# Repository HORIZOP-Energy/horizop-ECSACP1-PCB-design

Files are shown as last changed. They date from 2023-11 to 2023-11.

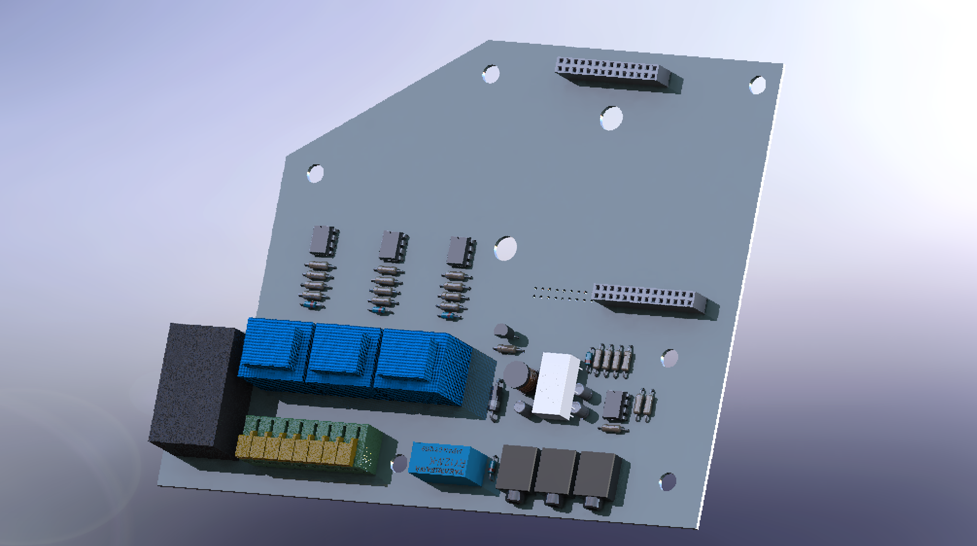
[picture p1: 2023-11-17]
Renders/Assembly_HE_ECSACP1_Prototype_PCB_V9_Final_Render.png

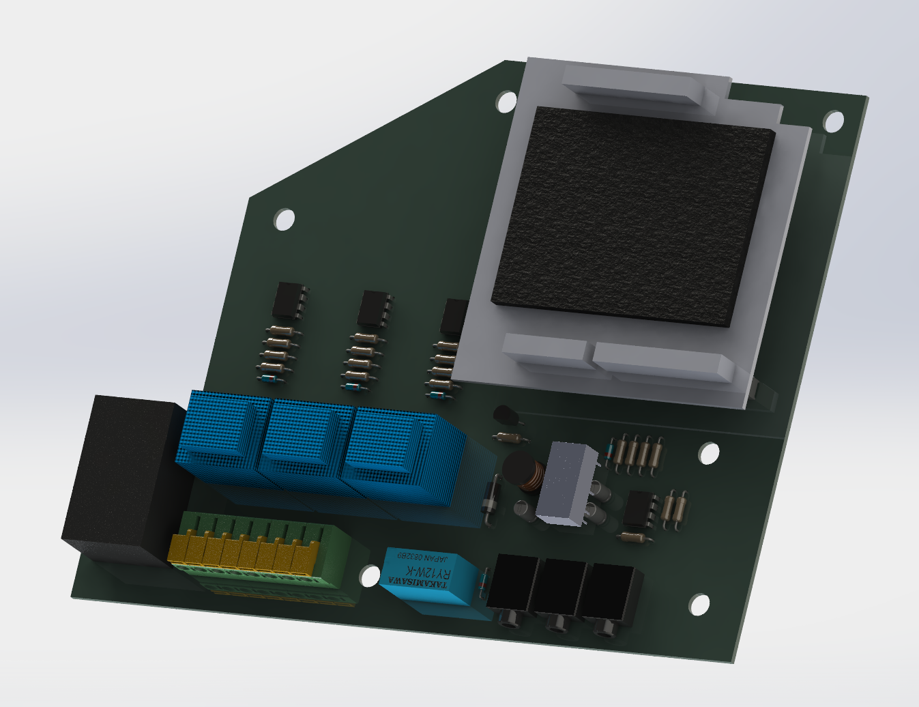
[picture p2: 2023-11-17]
Renders/Assembly_HE_ECSACP1_PCB_V9_With_ESP_WROVER_KIT_V4.1_Final_Render.png

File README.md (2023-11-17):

# HORIZOP Energy's EV Charging Station Prototype 1 PCB Design in KiCad and Solidworks

KiCad design files of a controller board for Type-2 charging (IEC 61851) of EVs.

See [Schematic](Media/HE_ECSACP1_PCB_Schematic.png) and [3d-view](Renders/Assembly_HE_ECSACP1_PCB_V9_With_ESP_WROVER_KIT_V4.1_Final_Render.png).

See [horizop-ECSACP1-firmware](https://github.com/HORIZOP-Energy/horizop-ECSACP1-firmware) for more 
information on the entire prototype.

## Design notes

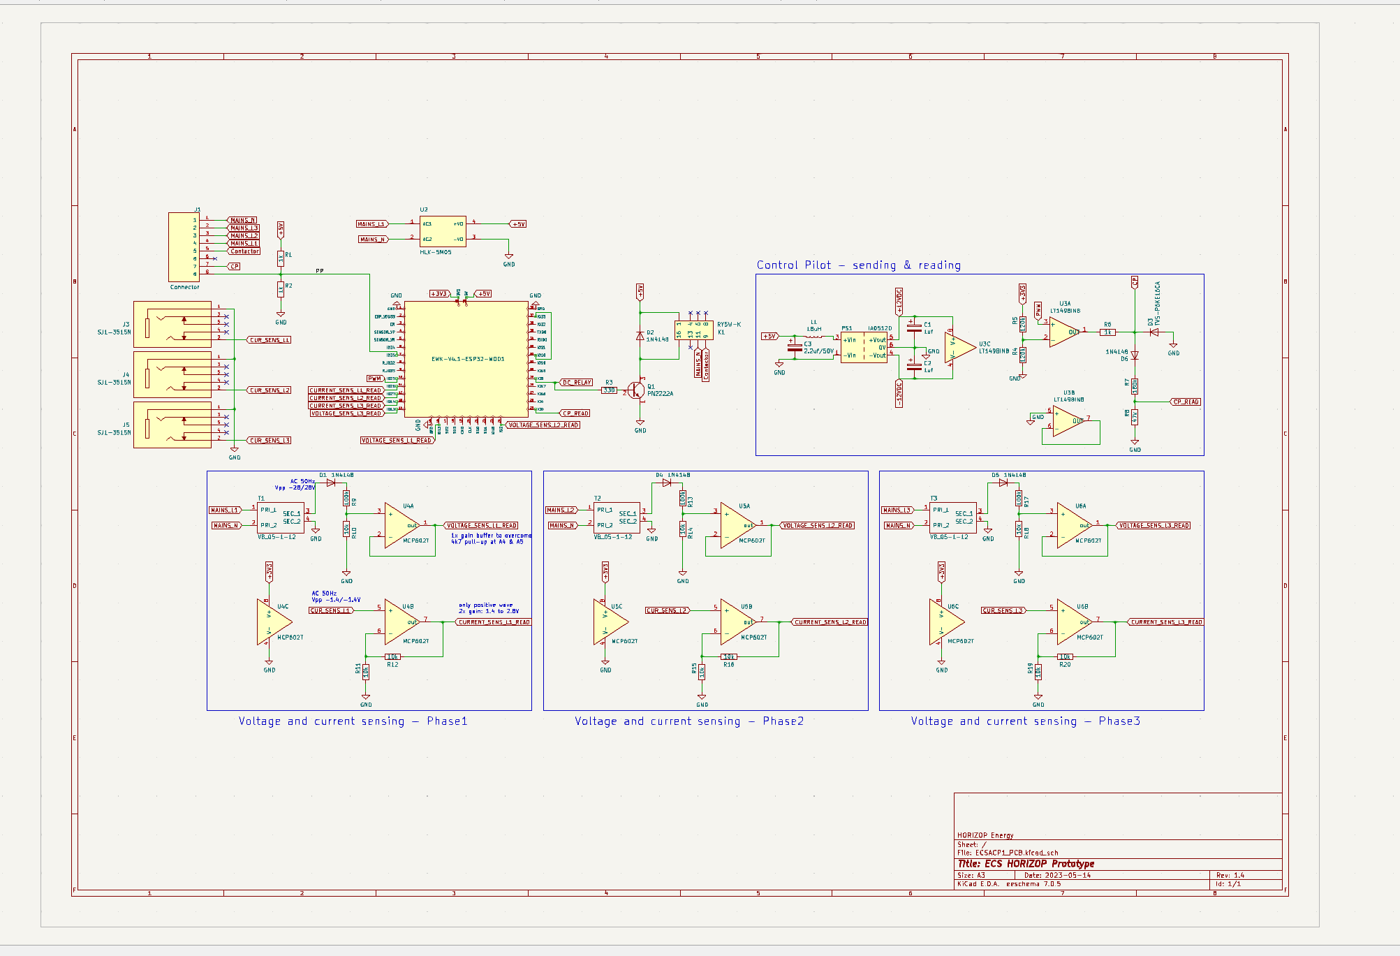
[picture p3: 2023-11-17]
Media/HE_ECSACP1_Prototype_PCB_V9_Final_Schematic.png

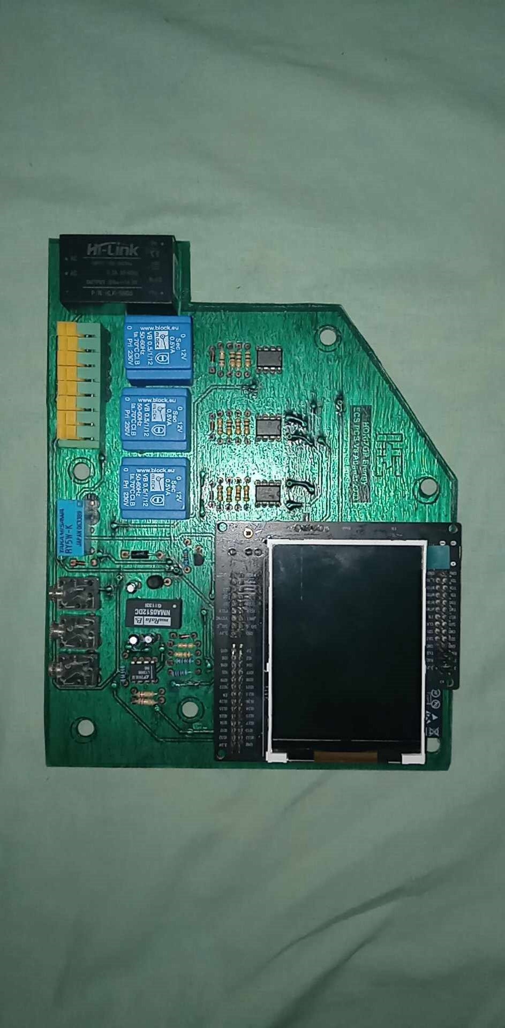
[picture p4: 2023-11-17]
Media/HE_ECSACP1_Prototype_PCB_V9_Final_Real_Picture.jpg

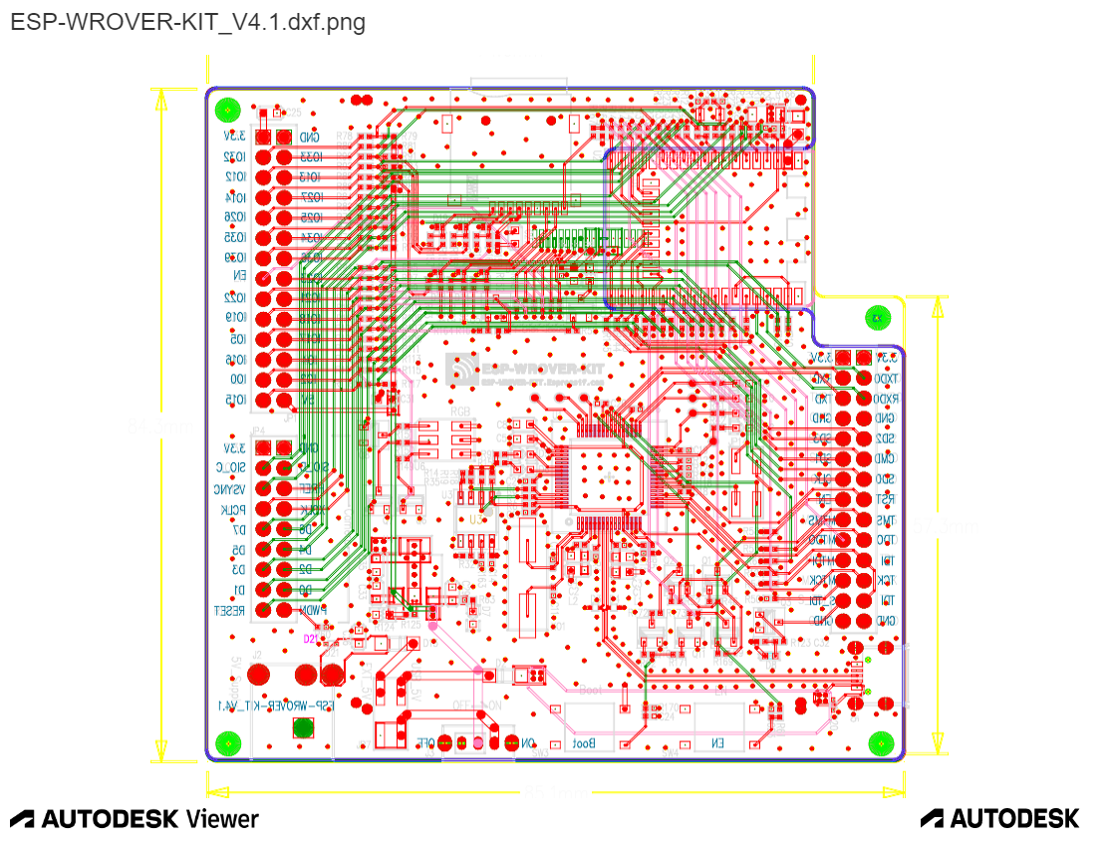
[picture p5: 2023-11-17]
Resources/ESP_WROVER_KIT/ESP-WROVER-KIT_V4.1/ESP-WROVER-KIT_V4.1.dxf.png

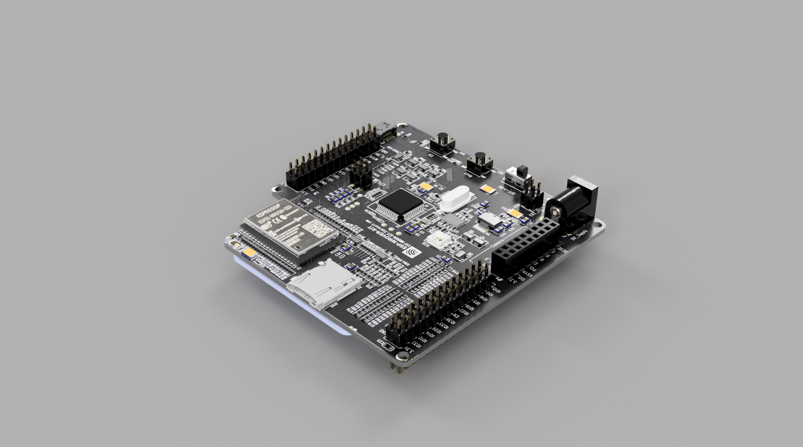
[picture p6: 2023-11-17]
Resources/ESP_WROVER_KIT/ESP-WROVER-KIT_V4.1/ESP-WROVER-KIT_V4.1 v11.png

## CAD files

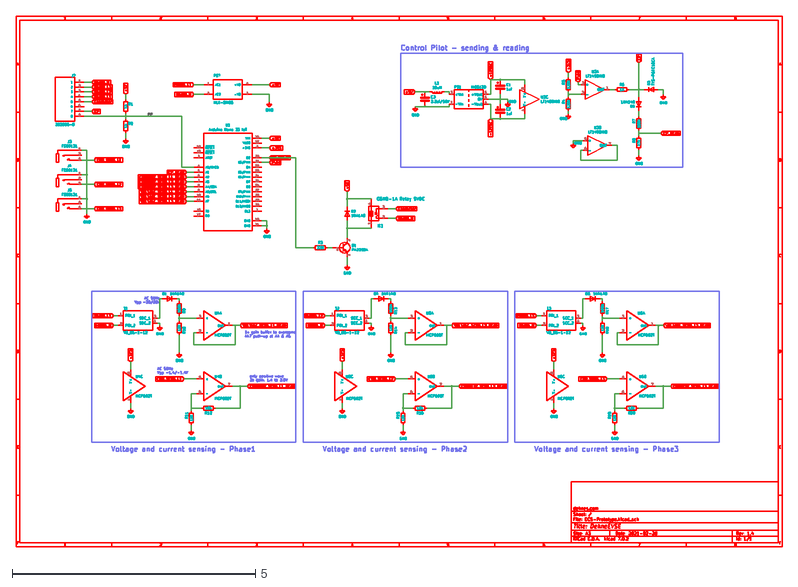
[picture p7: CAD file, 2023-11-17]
Renders/Assembly_HE_ECSACP1_Prototype_PCB_V9_Final.dxf
15.7 x 10.9

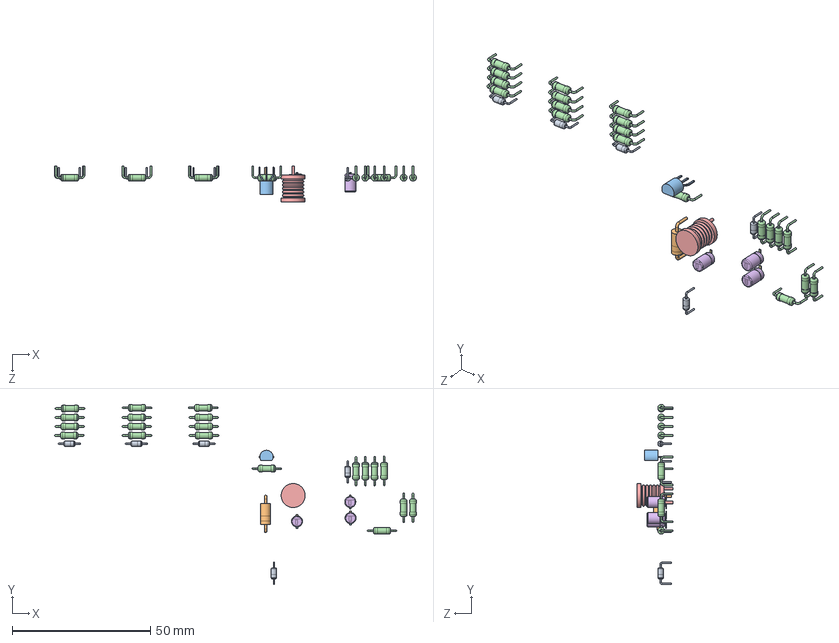
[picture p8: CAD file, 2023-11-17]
SOLIDWORKS_Files/HE_ECSACP1_PCB_V9_Final/PCB_KiCAD_HE_ECSACP1_PCB_V9.SLDASM
131.1 x 65.2 x 13.1 mm
E-CHIP_D4_L7_ELEMENT x 3
E-CHIP_D4_LEAD- x 3
E-CHIP_D4_LEAD_X2_FF0B_X0_ x 3

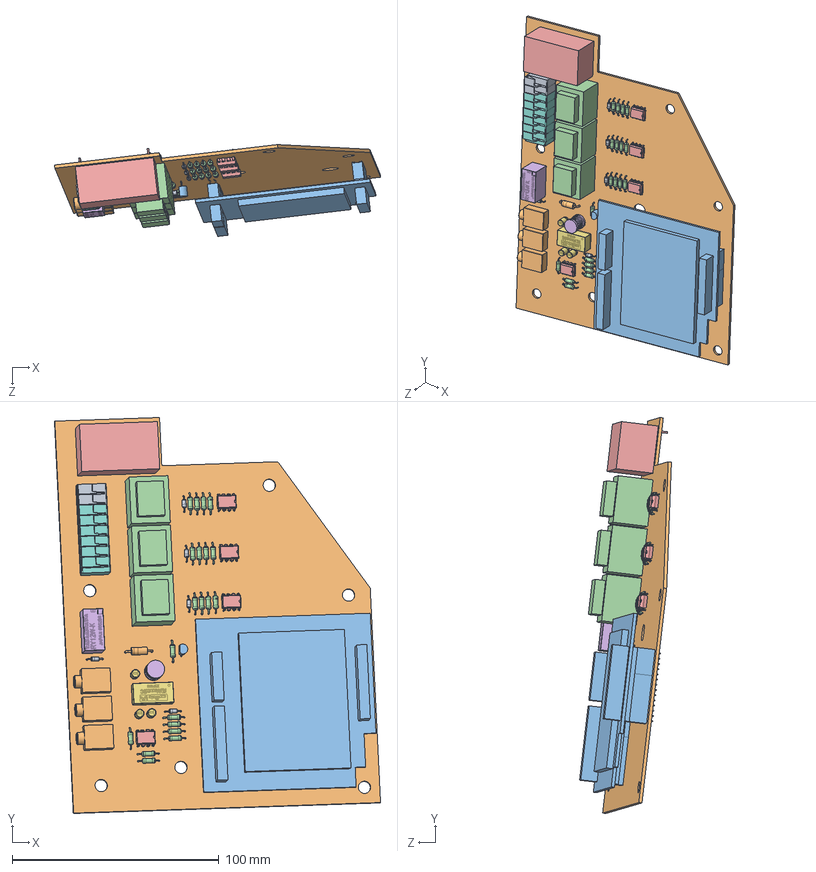
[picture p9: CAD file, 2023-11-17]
SOLIDWORKS_Files/HE_ECSACP1_PCB_V9_With_ESP_WROVER_KIT_V4.1_Final/Assembly_HE_ECSACP1_PCB_V9_With_ESP_WROVER_KIT_V4.1_Final.SLDASM
157.7 x 191.5 x 44.4 mm
E-CHIP_D4_L7_ELEMENT x 3
E-CHIP_D4_LEAD- x 3
E-CHIP_D4_LEAD_X2_FF0B_X0_ x 3
ECS-Prototype PCB
zl262-18d_p2-54_l23-36_w5_h8-5 v1 x 4
vb 0,5-1-12 x 3
HLK-5M05
User Library-TAKAMISAWA RY12W-K
mps_dcdc_nma_dc_a
DG142R-6-5.08
DG142R-2-5.08
sj1-3513n x 3
ESP-WROVER_KIT_V4.1_HE_ECSACP1_PCB_V9

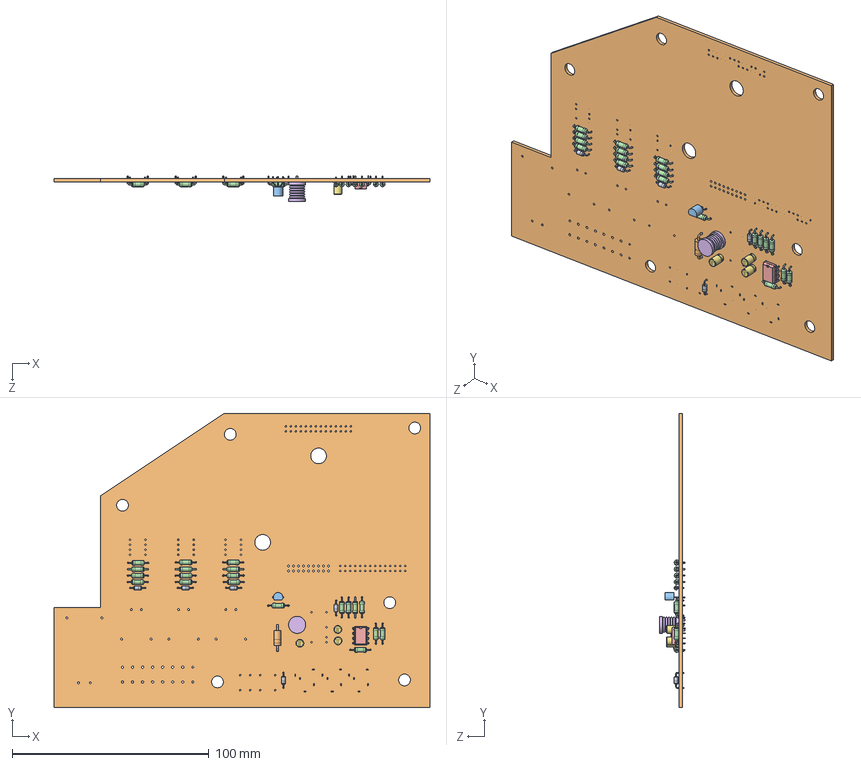
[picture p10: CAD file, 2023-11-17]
SOLIDWORKS_Files/HE_ECSACP1_PCB_V9_With_ESP_WROVER_KIT_V4.1_Final/PCB KiCAD.SLDASM
191.0 x 149.5 x 13.3 mm
E-CHIP_D4_L7_ELEMENT x 3
E-CHIP_D4_LEAD- x 3
E-CHIP_D4_LEAD_X2_FF0B_X0_ x 3
ECS-Prototype PCB

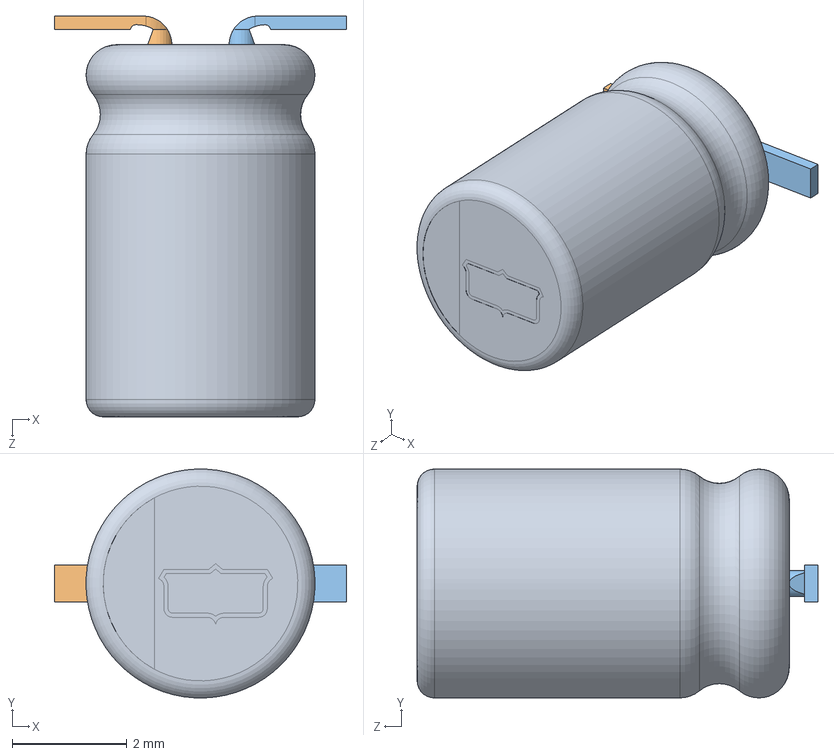
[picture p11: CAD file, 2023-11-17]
SOLIDWORKS_Files/HE_ECSACP1_PCB_V9_Final/E-CHIP_D4_L7__NORMAL_COATED-CASE_STRUCTURE_HE_ECSACP1_PCB_V9.SLDASM
5.10 x 4.00 x 7.00 mm
E-CHIP_D4_L7_ELEMENT
E-CHIP_D4_LEAD-
E-CHIP_D4_LEAD_X2_FF0B_X0_

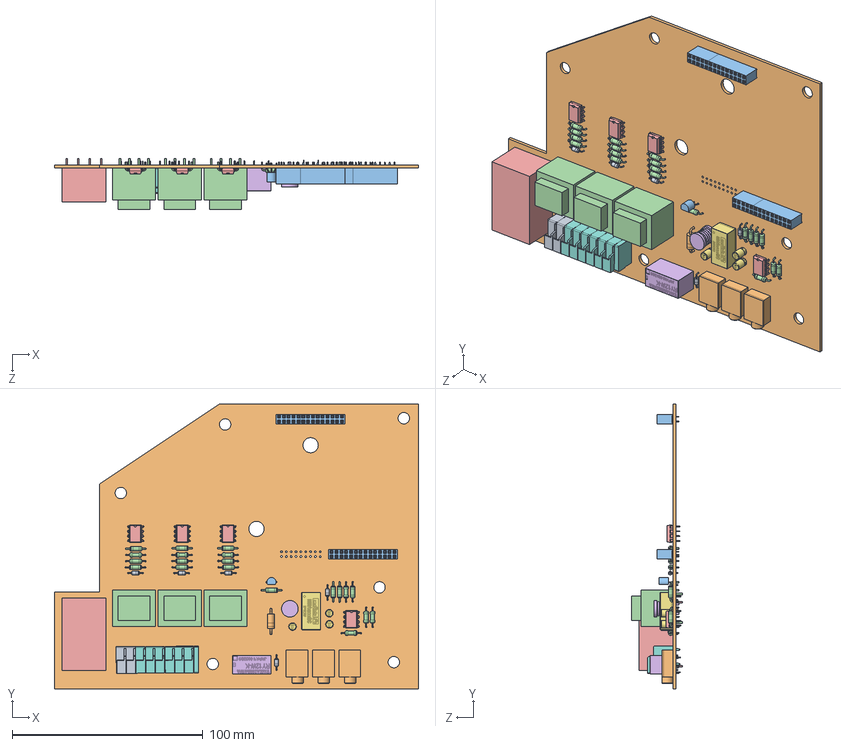
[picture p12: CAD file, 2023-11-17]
SOLIDWORKS_Files/HE_ECSACP1_PCB_V9_Final/Assembly_HE_ECSACP1_PCB_V9_Final.SLDASM
191.0 x 149.5 x 27.0 mm
SOLID_4_HE_ECSACP1_PCB_V9 x 4
E-CHIP_D4_L7_ELEMENT x 3
E-CHIP_D4_LEAD- x 3
E-CHIP_D4_LEAD_X2_FF0B_X0_ x 3
Board_HE_ECSACP1_PCB_V9
zl262-18d_p2-54_l23-36_w5_h8-5 v1_HE_ECSACP1_PCB_V9 x 4
vb 0,5-1-12_HE_ECSACP1_PCB_V9 x 3
HLK-5M05_HE_ECSACP1_PCB_V9
User Library-TAKAMISAWA RY12W-K_HE_ECSACP1_PCB_V9
mps_dcdc_nma_dc_a_HE_ECSACP1_PCB_V9
DG142R-6-5.08_HE_ECSACP1_PCB_V9
DG142R-2-5.08_HE_ECSACP1_PCB_V9
sj1-3513n_HE_ECSACP1_PCB_V9 x 3

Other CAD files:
SOLIDWORKS_Files/HE_ECSACP1_PCB_V9_With_ESP_WROVER_KIT_V4.1_Final/DIP-8_W7.62mm.SLDASM
SOLIDWORKS_Files/HE_ECSACP1_PCB_V9_Final/L_Radial_D8.7mm_P5.00mm_Fastron_07HCP_HE_ECSACP1_PCB_V9.SLDASM
SOLIDWORKS_Files/HE_ECSACP1_PCB_V9_With_ESP_WROVER_KIT_V4.1_Final/L_Radial_D8.7mm_P5.00mm_Fastron_07HCP.SLDASM
SOLIDWORKS_Files/HE_ECSACP1_PCB_V9_Final/D_DO-35_SOD27_P7.62mm_Horizontal_HE_ECSACP1_PCB_V9_HE_ECSACP1_PCB_V9.SLDASM
SOLIDWORKS_Files/HE_ECSACP1_PCB_V9_With_ESP_WROVER_KIT_V4.1_Final/R_Axial_DIN0207_L6.3mm_D2.5mm_P10.16mm_Horizontal.SLDASM
SOLIDWORKS_Files/HE_ECSACP1_PCB_V9_With_ESP_WROVER_KIT_V4.1_Final/E-CHIP_D4_L7__NORMAL_COATED-CASE_STRUCTURE.SLDASM
SOLIDWORKS_Files/HE_ECSACP1_PCB_V9_Final/DIP-8_W7.62mm_HE_ECSACP1_PCB_V9.SLDASM
SOLIDWORKS_Files/HE_ECSACP1_PCB_V9_Final/R_Axial_DIN0207_L6.3mm_D2.5mm_P10.16mm_Horizontal_HE_ECSACP1_PCB_V9.SLDASM
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

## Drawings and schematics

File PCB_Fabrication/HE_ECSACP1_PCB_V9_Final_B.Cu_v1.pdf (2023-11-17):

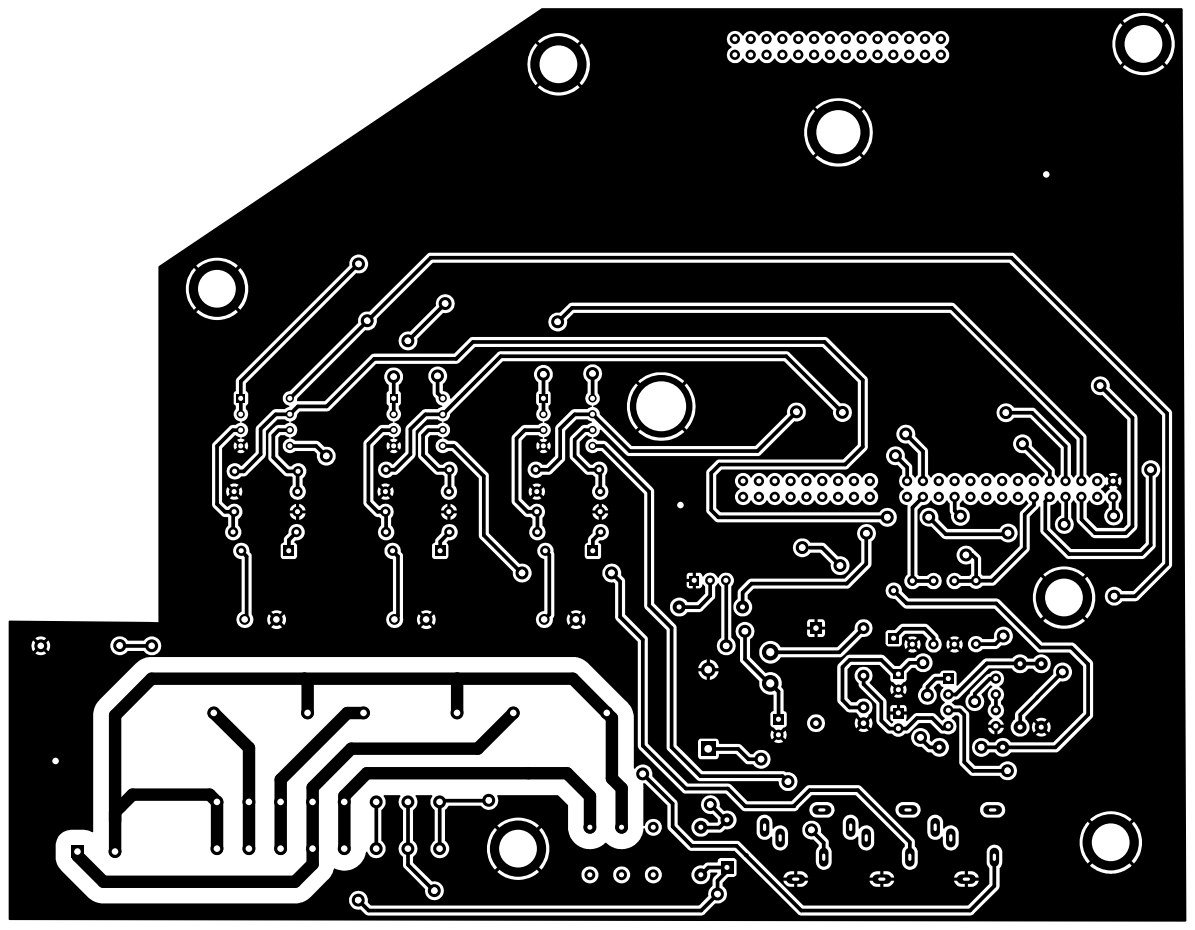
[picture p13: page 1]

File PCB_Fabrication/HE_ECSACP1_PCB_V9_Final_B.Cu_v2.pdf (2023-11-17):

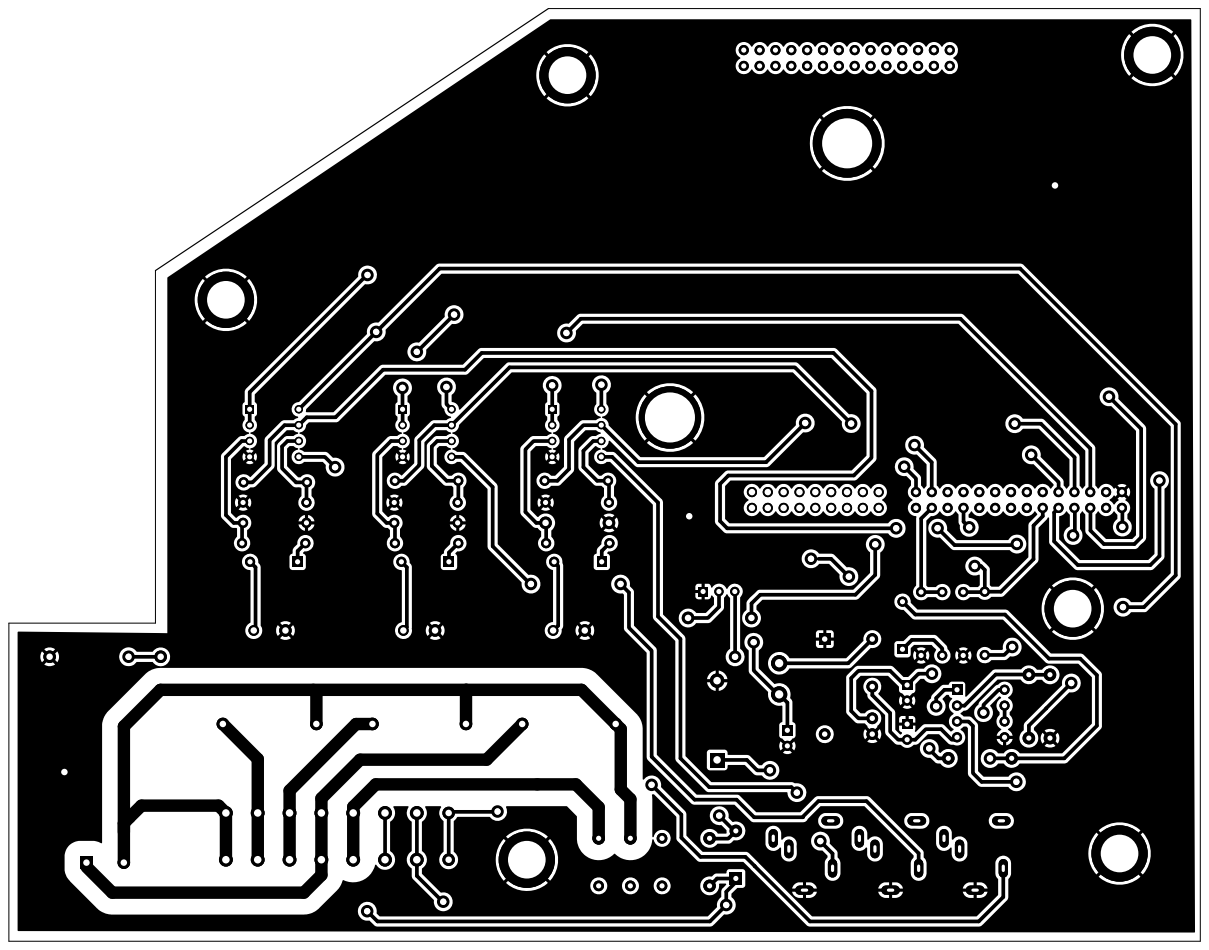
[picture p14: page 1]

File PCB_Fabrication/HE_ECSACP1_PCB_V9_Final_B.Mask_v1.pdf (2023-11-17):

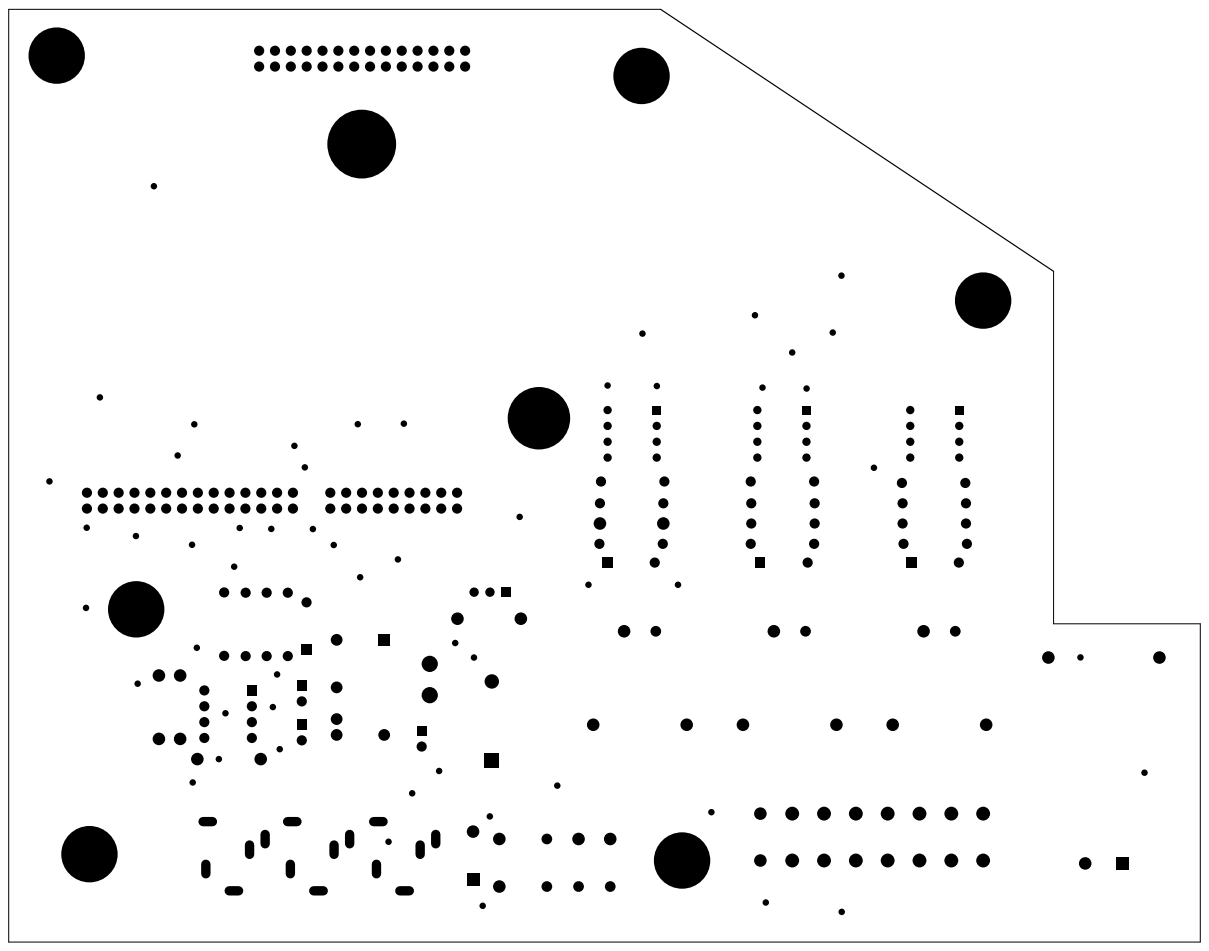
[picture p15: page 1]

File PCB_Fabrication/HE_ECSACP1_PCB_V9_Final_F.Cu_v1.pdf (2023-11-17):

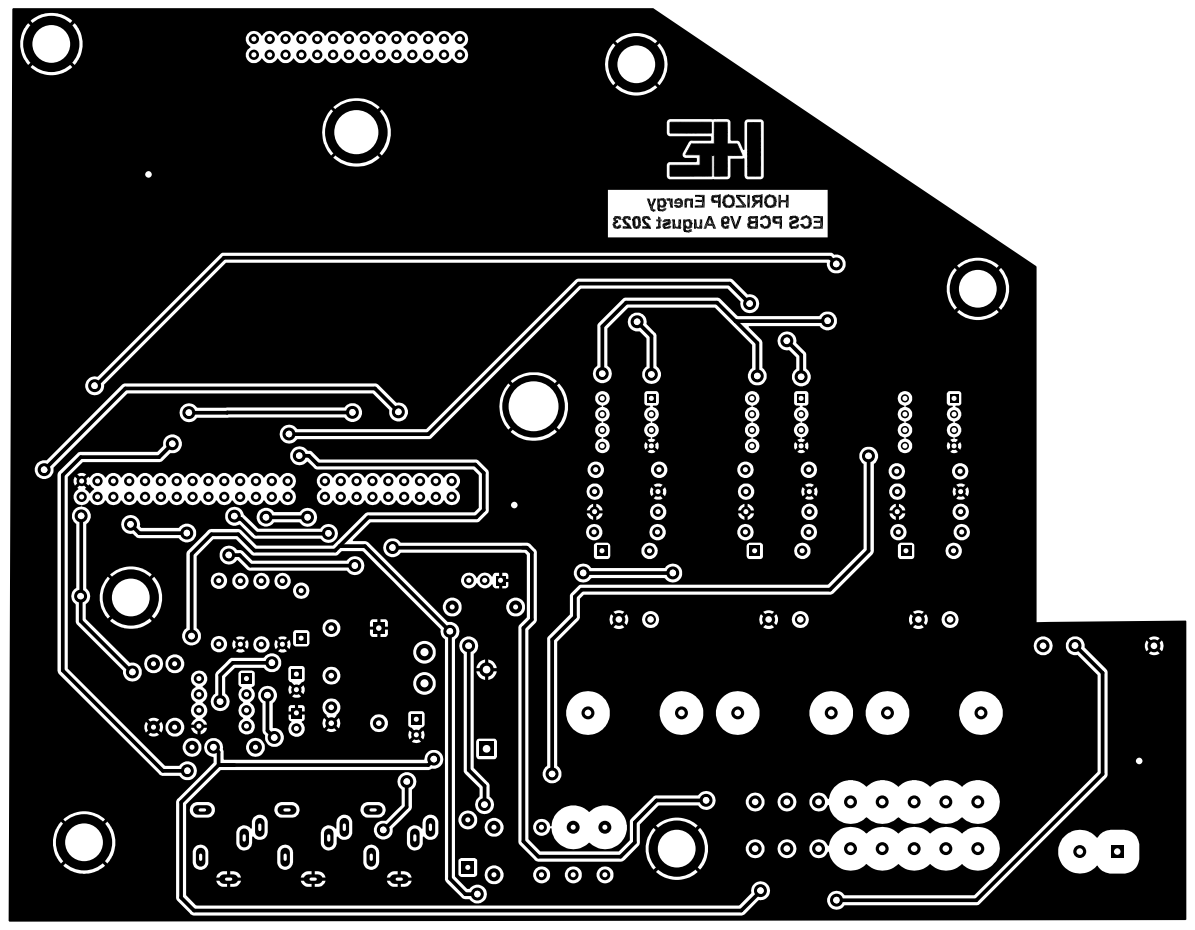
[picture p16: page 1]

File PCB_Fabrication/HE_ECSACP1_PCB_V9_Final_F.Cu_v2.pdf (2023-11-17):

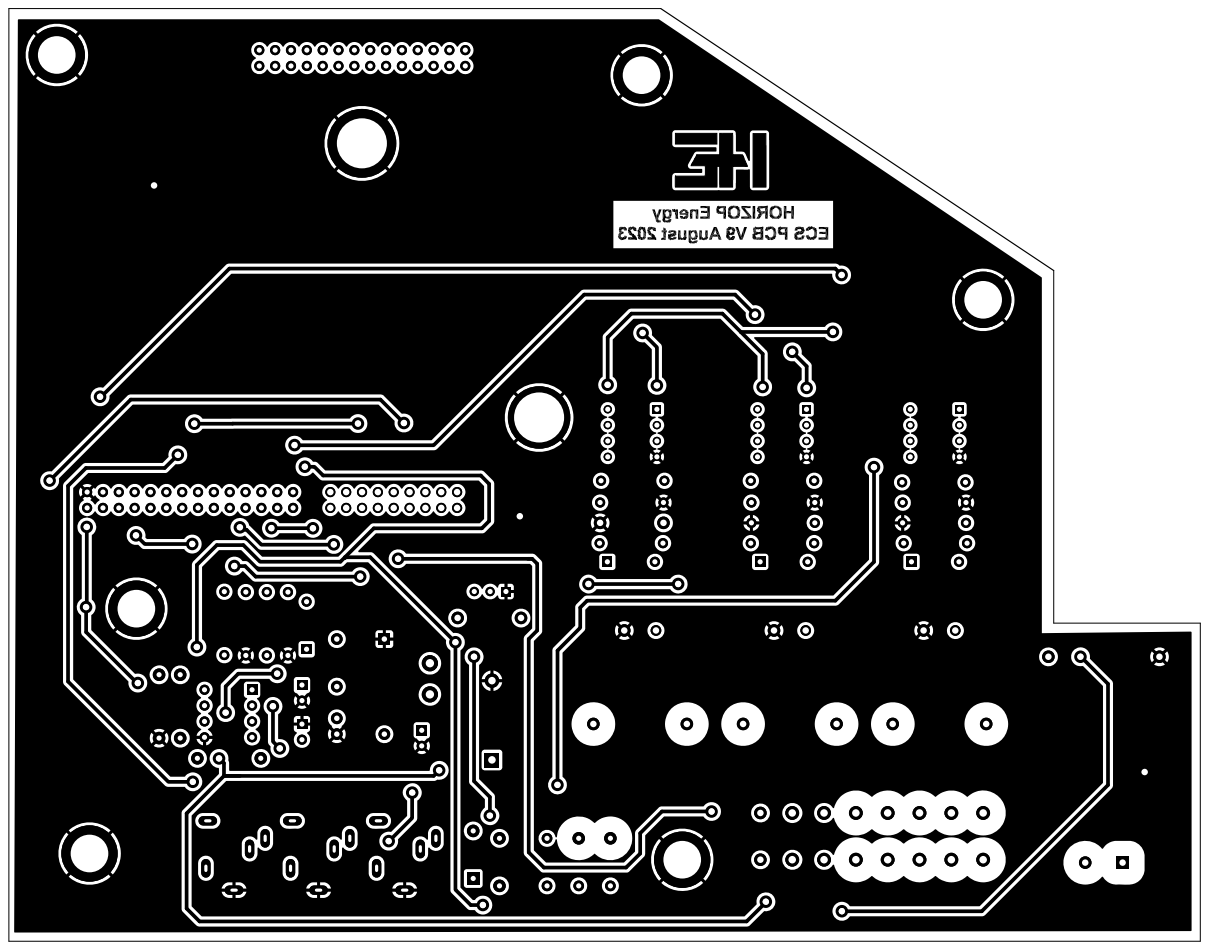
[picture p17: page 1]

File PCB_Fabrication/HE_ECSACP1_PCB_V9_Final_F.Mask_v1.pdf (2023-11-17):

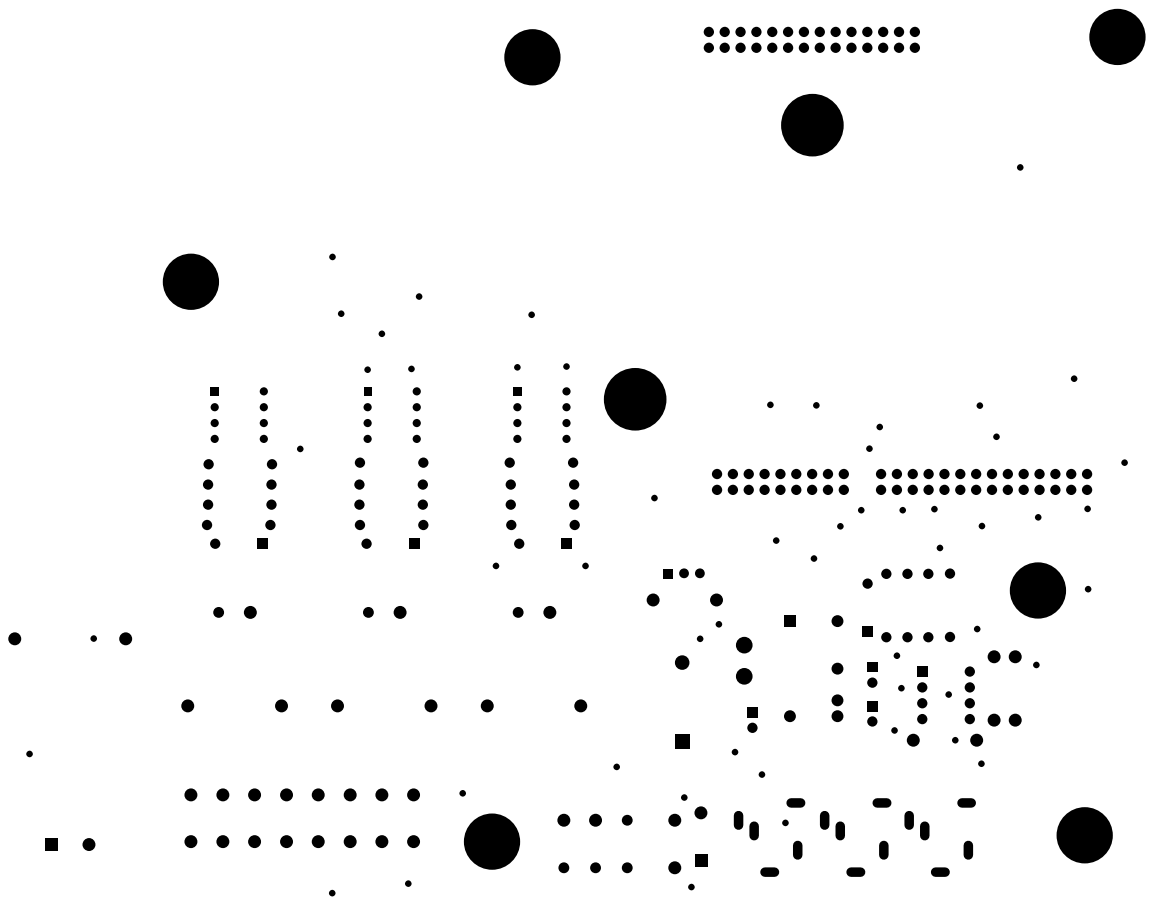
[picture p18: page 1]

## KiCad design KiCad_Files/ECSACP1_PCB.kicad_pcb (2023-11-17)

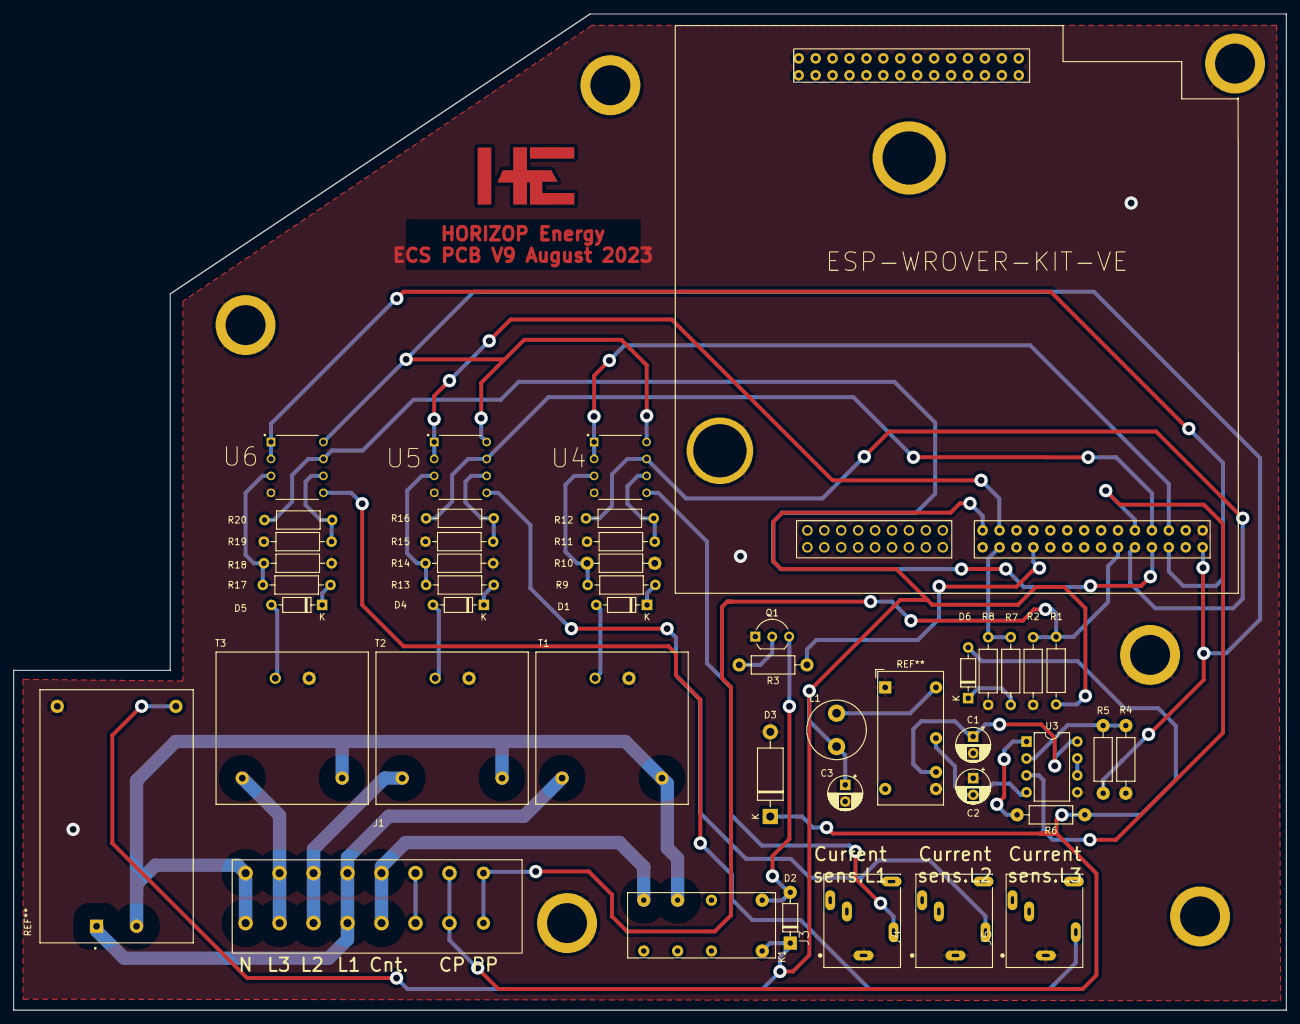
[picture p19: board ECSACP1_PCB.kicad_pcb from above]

Board: 2 copper layers, 191.0 x 149.5 mm, 43 parts (1 on the bottom side), 41 nets.

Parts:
C1, C2: 1uf; CP_Radial_D5.0mm_P2.50mm
C3: 2.2uf/50V; CP_Radial_D5.0mm_P2.50mm
D1, D2, D4, D5, D6: 1N4148; D_DO-35_SOD27_P7.62mm_Horizontal
D3: TVS-P6KE16CA; D_DO-15_P12.70mm_Horizontal
J1: Connector1; Bornier la5dher
J3, J4, J5: SJ1-3515N; CUI_SJ1-3515N
L1: 18uH; L_Radial_D8.7mm_P5.00mm_Fastron_07HCP
Q1: PN2222A; TO-92_Inline_Wide
R1, R2, R6: 1k; R_Axial_DIN0207_L6.3mm_D2.5mm_P10.16mm_Horizontal
R3: 330; R_Axial_DIN0207_L6.3mm_D2.5mm_P10.16mm_Horizontal
R4, R5: 120k; R_Axial_DIN0207_L6.3mm_D2.5mm_P10.16mm_Horizontal
R7: 180k; R_Axial_DIN0207_L6.3mm_D2.5mm_P10.16mm_Horizontal
R8: 47k; R_Axial_DIN0207_L6.3mm_D2.5mm_P10.16mm_Horizontal
R9, R13, R17: 100k; R_Axial_DIN0207_L6.3mm_D2.5mm_P10.16mm_Horizontal
R10, R11, R12, R14, R15, R16, R18, R19, R20: 10k; R_Axial_DIN0207_L6.3mm_D2.5mm_P10.16mm_Horizontal
Ref**: ESP-WROVER-KIT-VE
T1, T2, T3: VB_05-1-12
U3: LT1498IN8; DIP-8_W7.62mm
U4, U5, U6: MCP602T; DIP787W46P254L927H533Q8

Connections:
+3V3: R5.2, Ref**.1, U4.8, U5.8, U6.8
+5V: C3.1, D2.1, L1.2, R1.2, Ref**.28
+12VDC: C1.1, U3.8
-12VDC: C2.2, U3.4
/PP: J1.13, R1.1, R2.2, Ref**.6
CP: D3.1, D6.2, J1.14, R6.1
CP_READ: R7.1, R8.2, Ref**.13
CURRENT_SENS_L1_READ: R12.2, Ref**.5, U4.7
CURRENT_SENS_L2_READ: R16.2, Ref**.18, U5.7
CURRENT_SENS_L3_READ: R20.2, Ref**.4, U6.7
CUR_SENS_L1: J3.2, U4.5
CUR_SENS_L2: J4.2, U5.5
CUR_SENS_L3: J5.2, U6.5
DC_RELAY: R3.1, Ref**.11
GND: C1.2, C2.1, C3.2, D3.2, J3.1, J4.1, J5.1, Q1.1, R2.1, R4.1, R8.1, R10.2, R11.1, R14.2, R15.1, R18.2, R19.1, Ref**.15, T1.4, T2.4, T3.2, U3.5, U4.4, U5.4, U6.4
MAINS_L1: J1.17, T1.1
MAINS_L2: J1.18, T2.1
MAINS_L3: J1.19, T3.1
MAINS_N: J1.20, T1.2, T2.2, T3.2
unnamed: D1.1, R9.1
unnamed: D1.2, T1.3
unnamed: D2.2, Q1.3
unnamed: D4.1, R13.1
unnamed: D4.2, T2.3
unnamed: D5.1, R17.1
unnamed: D5.2, T3.3
unnamed: D6.1, R7.2
unnamed: Q1.2, R3.2
unnamed: R4.2, R5.1, U3.2
unnamed: R6.2, U3.1
unnamed: R9.2, R10.1, U4.3
unnamed: R11.2, R12.1, U4.6
unnamed: R13.2, R14.1, U5.3
unnamed: R15.2, R16.1, U5.6
unnamed: R17.2, R18.1, U6.3
unnamed: R19.2, R20.1, U6.6
unnamed: U3.6, U3.7
PWM: Ref**.19, U3.3
VOLTAGE_SENS_L1_READ: Ref**.17, U4.1, U4.2
VOLTAGE_SENS_L2_READ: Ref**.27, U5.1, U5.2
VOLTAGE_SENS_L3_READ: Ref**.3, U6.1, U6.2

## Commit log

2023-11-17 Initial commit PCB version 1
    [ECS-Prototype.dxf, ECS-Prototype.kicad_pcb, ECS-Prototype.kicad_sch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]
2023-11-17 first modifications for pcb design v2 1mm
    [ECS-Prototype.kicad_pcb]
2023-11-17 modifications for pcb design: version 2.2 1mm
    [ECS-Prototype.kicad_pcb]
2023-11-17 modifications for pcb design: version 3
    [ECS-Prototype.dxf, ECS-Prototype.kicad_pcb, ECS-Prototype.kicad_sch]
2023-11-17 modifications for pcb design version 4: like v3 but with both faces soldering
    [ECS-Prototype.kicad_pcb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]
2023-11-17 modifications for pcb design v6: like v4 but with modified jack and 0.8 vias
    [ECS-Prototype-B_Cu.gbl, ECS-Prototype-B_Mask.gbs, ECS-Prototype-B_Silkscreen.gbo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]
2023-11-17 modifications for pcb design v7: like v5 but with modified jack and 0.8mm vias
    [ECS-Prototype-B_Cu.gbl, ECS-Prototype-B_Mask.gbs, ECS-Prototype-B_Silkscreen.gbo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]
2023-11-17 final printed version: v9: like v7 but with 0.6mm vias
    [ECS-Prototype.kicad_pcb, ECSACP1_PCB.dxf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]
2023-11-17 added 3d renderings and media
    [282856-8--3DModel-STEP-1.STEP, 282856-8.SLDPRT, 282856-8.step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]
2023-11-17 added solidworks files and renders
    [Assembly_HE_ECSACP1_PCB_V9_Final.SLDASM, Assembly_HE_ECSACP1_PCB_V9_With_ESP_WROVER_KIT_V4.1_Final.SLDASM, Assembly_HE_ECSACP1_Prototype_PCB_V9_Final.dxf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]
